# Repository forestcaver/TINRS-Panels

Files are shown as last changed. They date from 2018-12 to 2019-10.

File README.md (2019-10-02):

# TINRS-Panels
Tuesday Panel - verified and built

Wobbler Panel - verified and built

Rectangular Thing Panel - verified and built

Hedge Trimmer pcb and panel (Edgecutter with thonkiconn jacks and LP4OA1PBCTG led switch) - verified and built (one hole is not drilled - oops ! I'll update the gerber soon !)

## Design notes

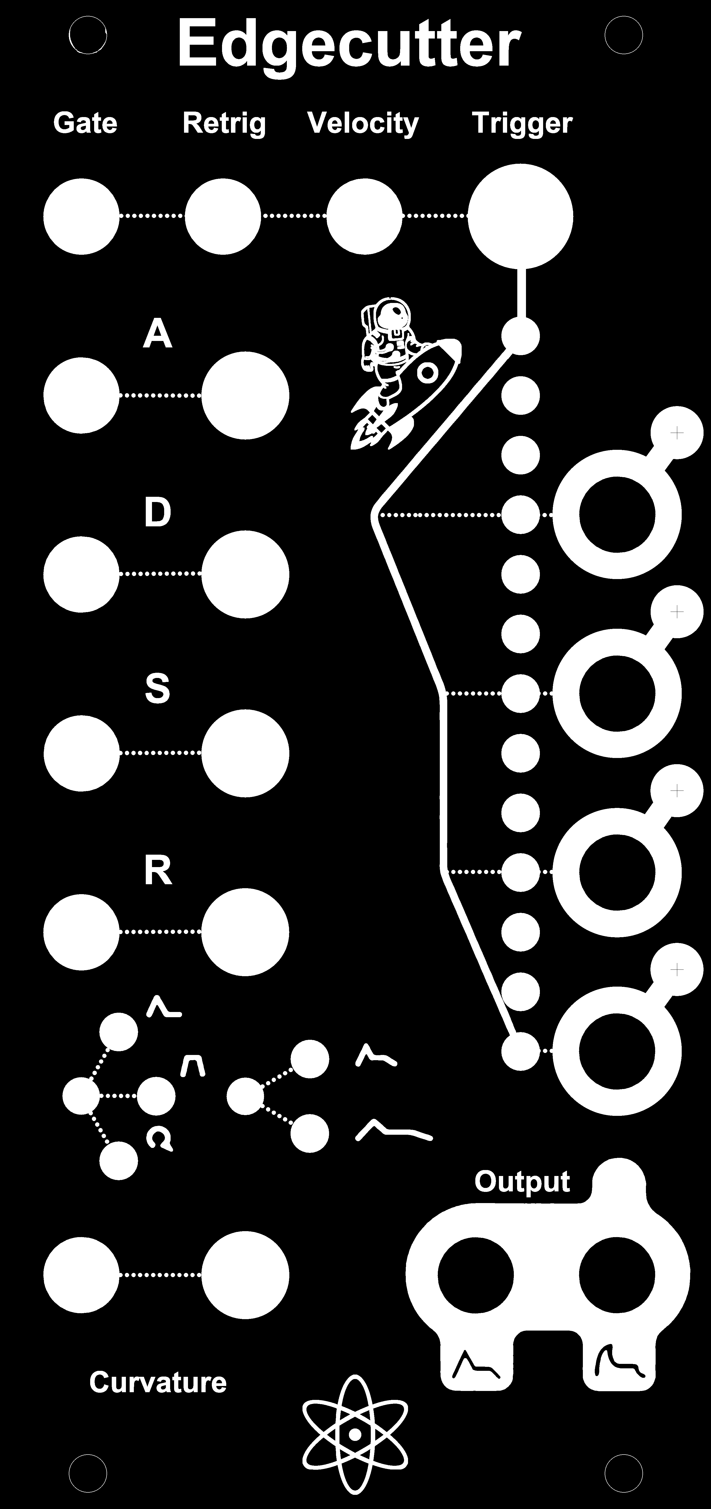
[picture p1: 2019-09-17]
HT_06.bmp

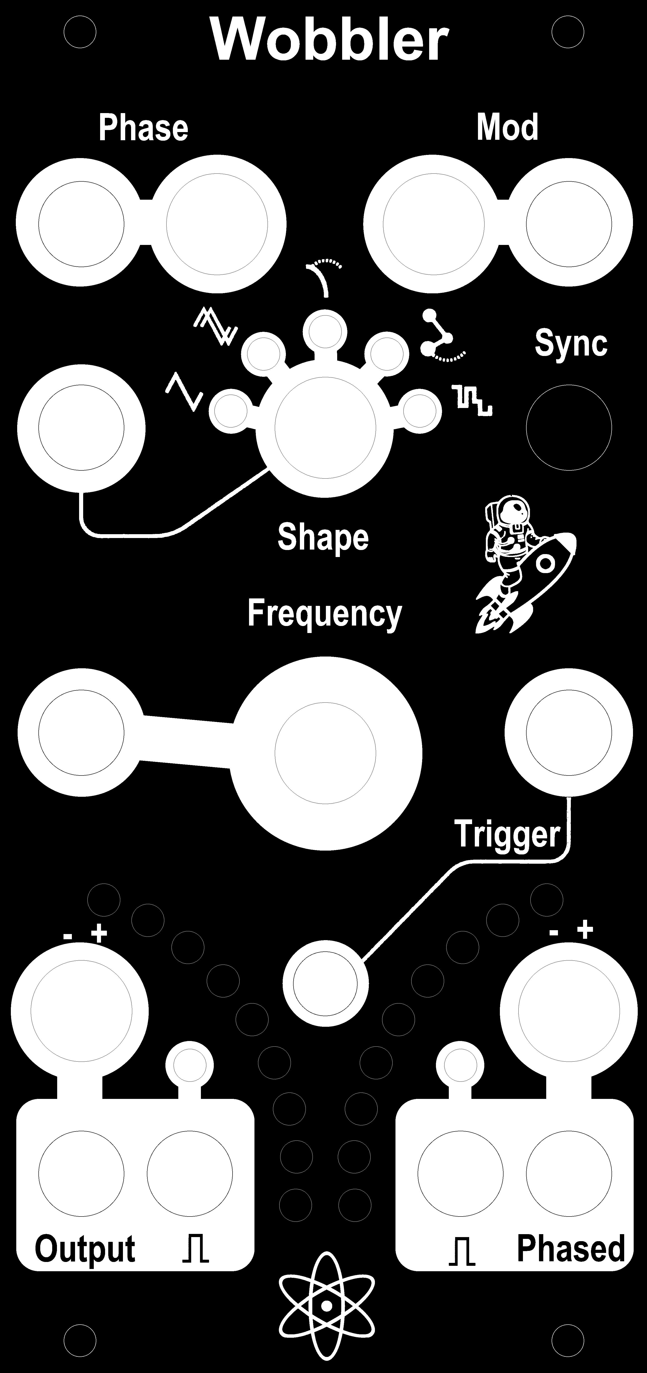
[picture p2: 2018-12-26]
AJH_Wob_01.bmp

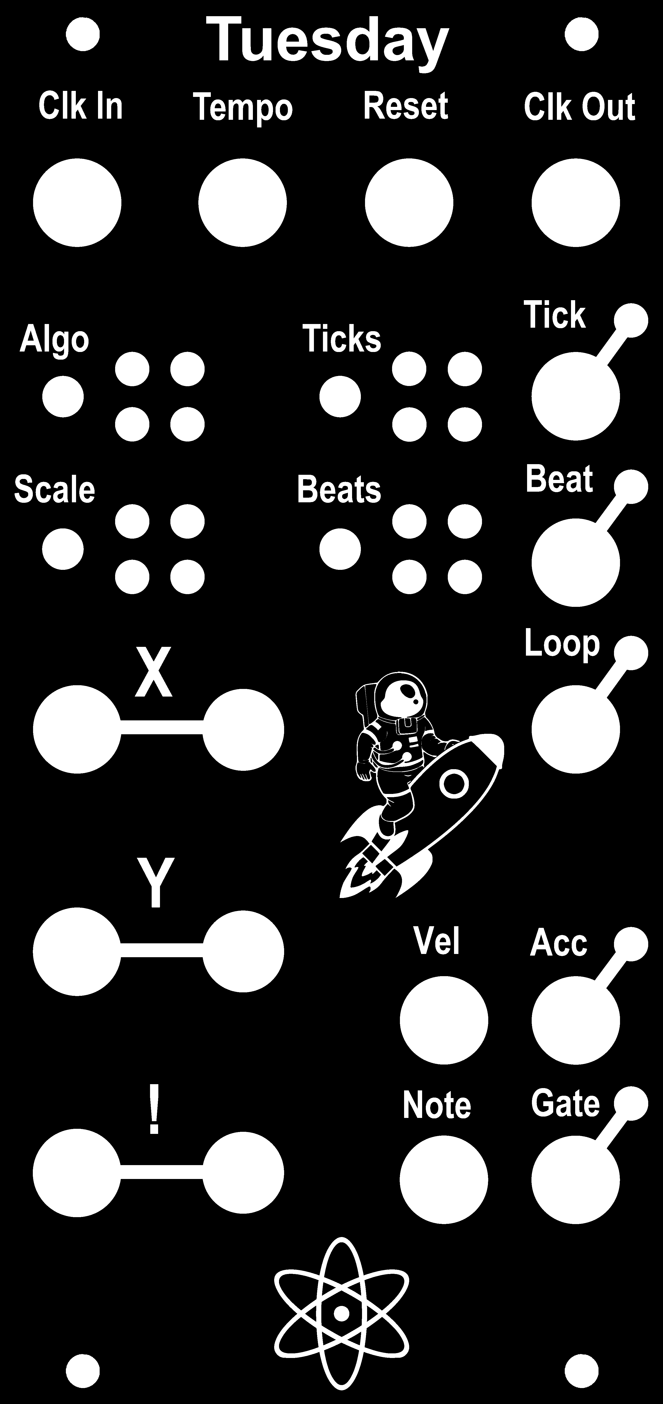
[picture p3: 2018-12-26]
Tue_Panel_AJH_01.bmp

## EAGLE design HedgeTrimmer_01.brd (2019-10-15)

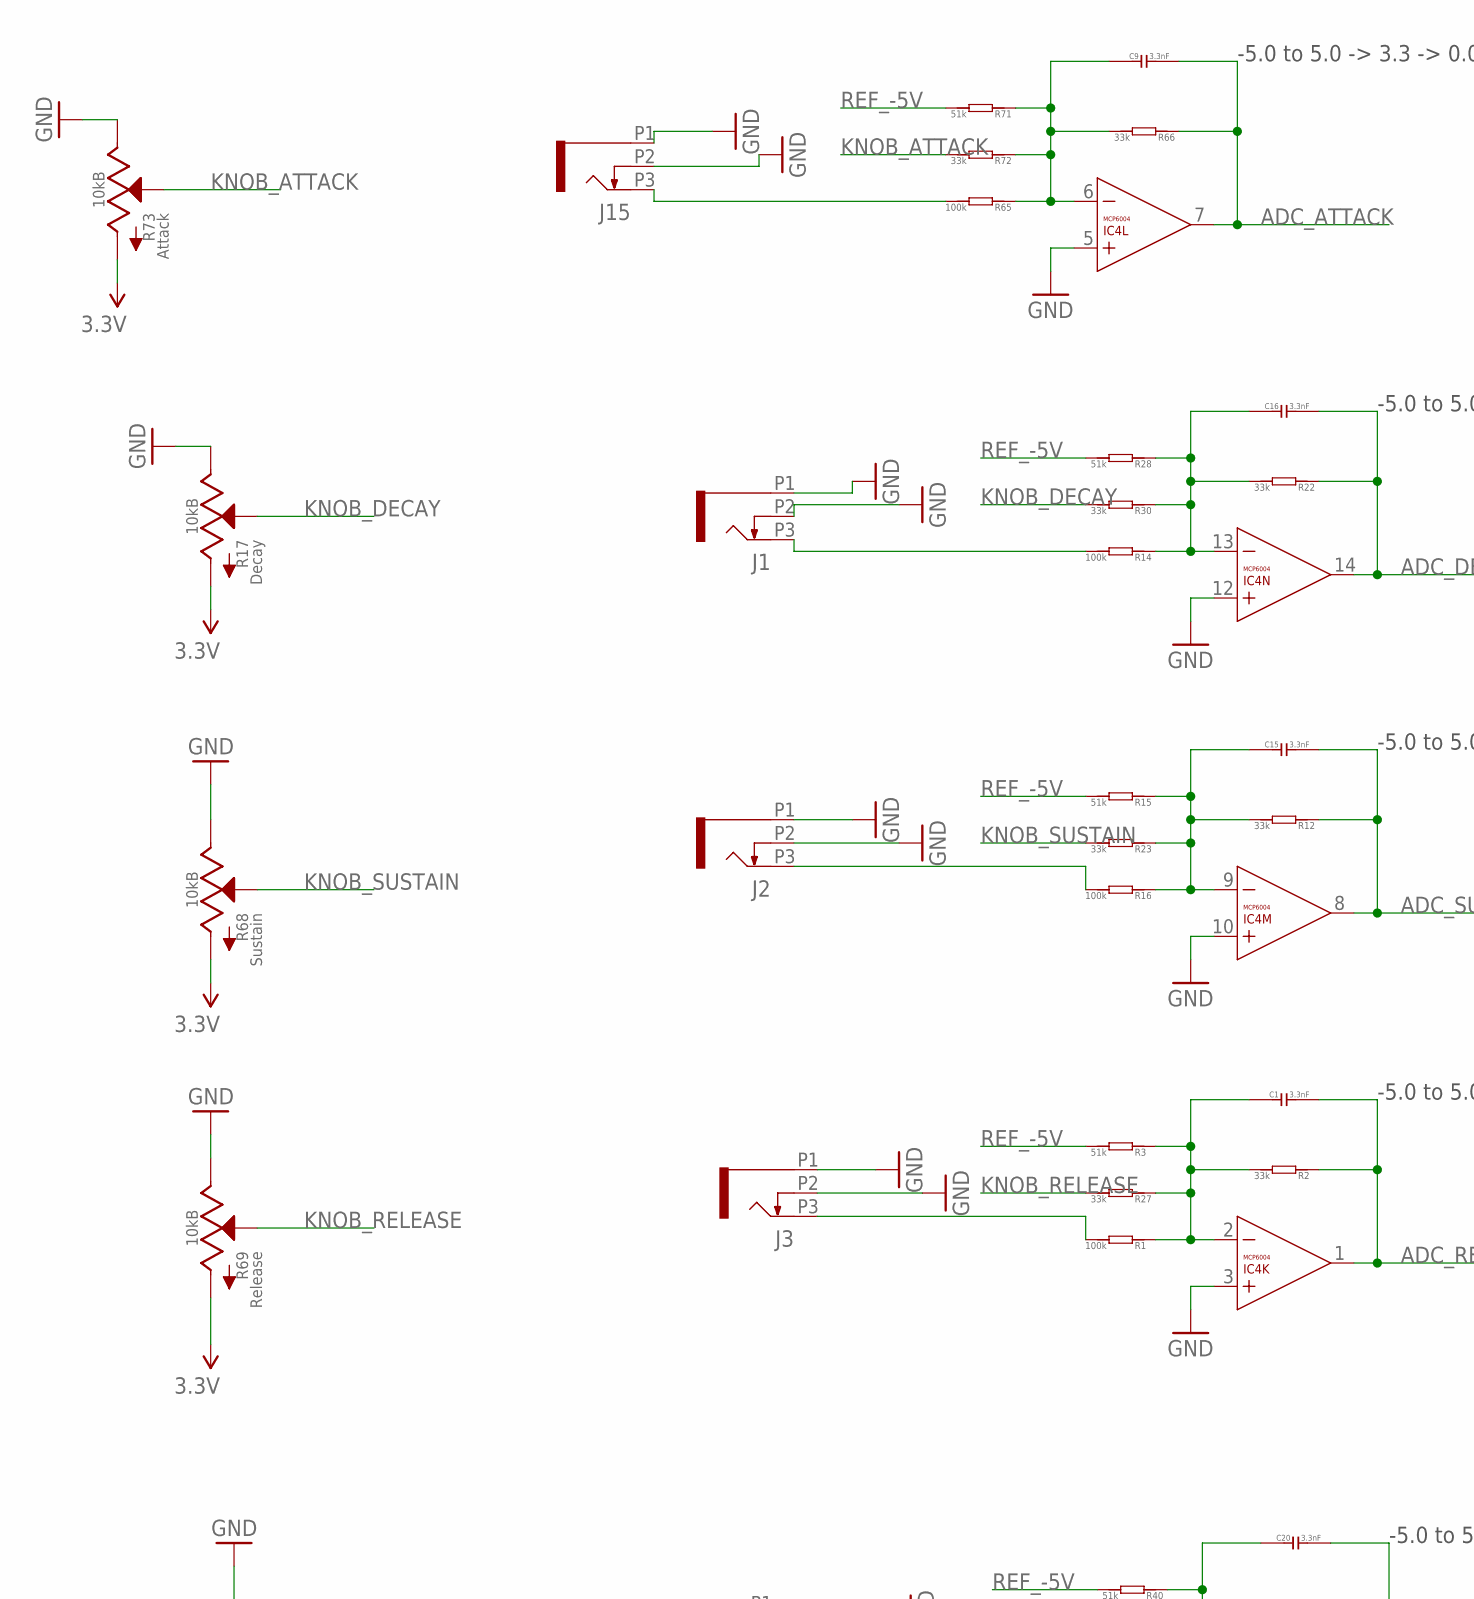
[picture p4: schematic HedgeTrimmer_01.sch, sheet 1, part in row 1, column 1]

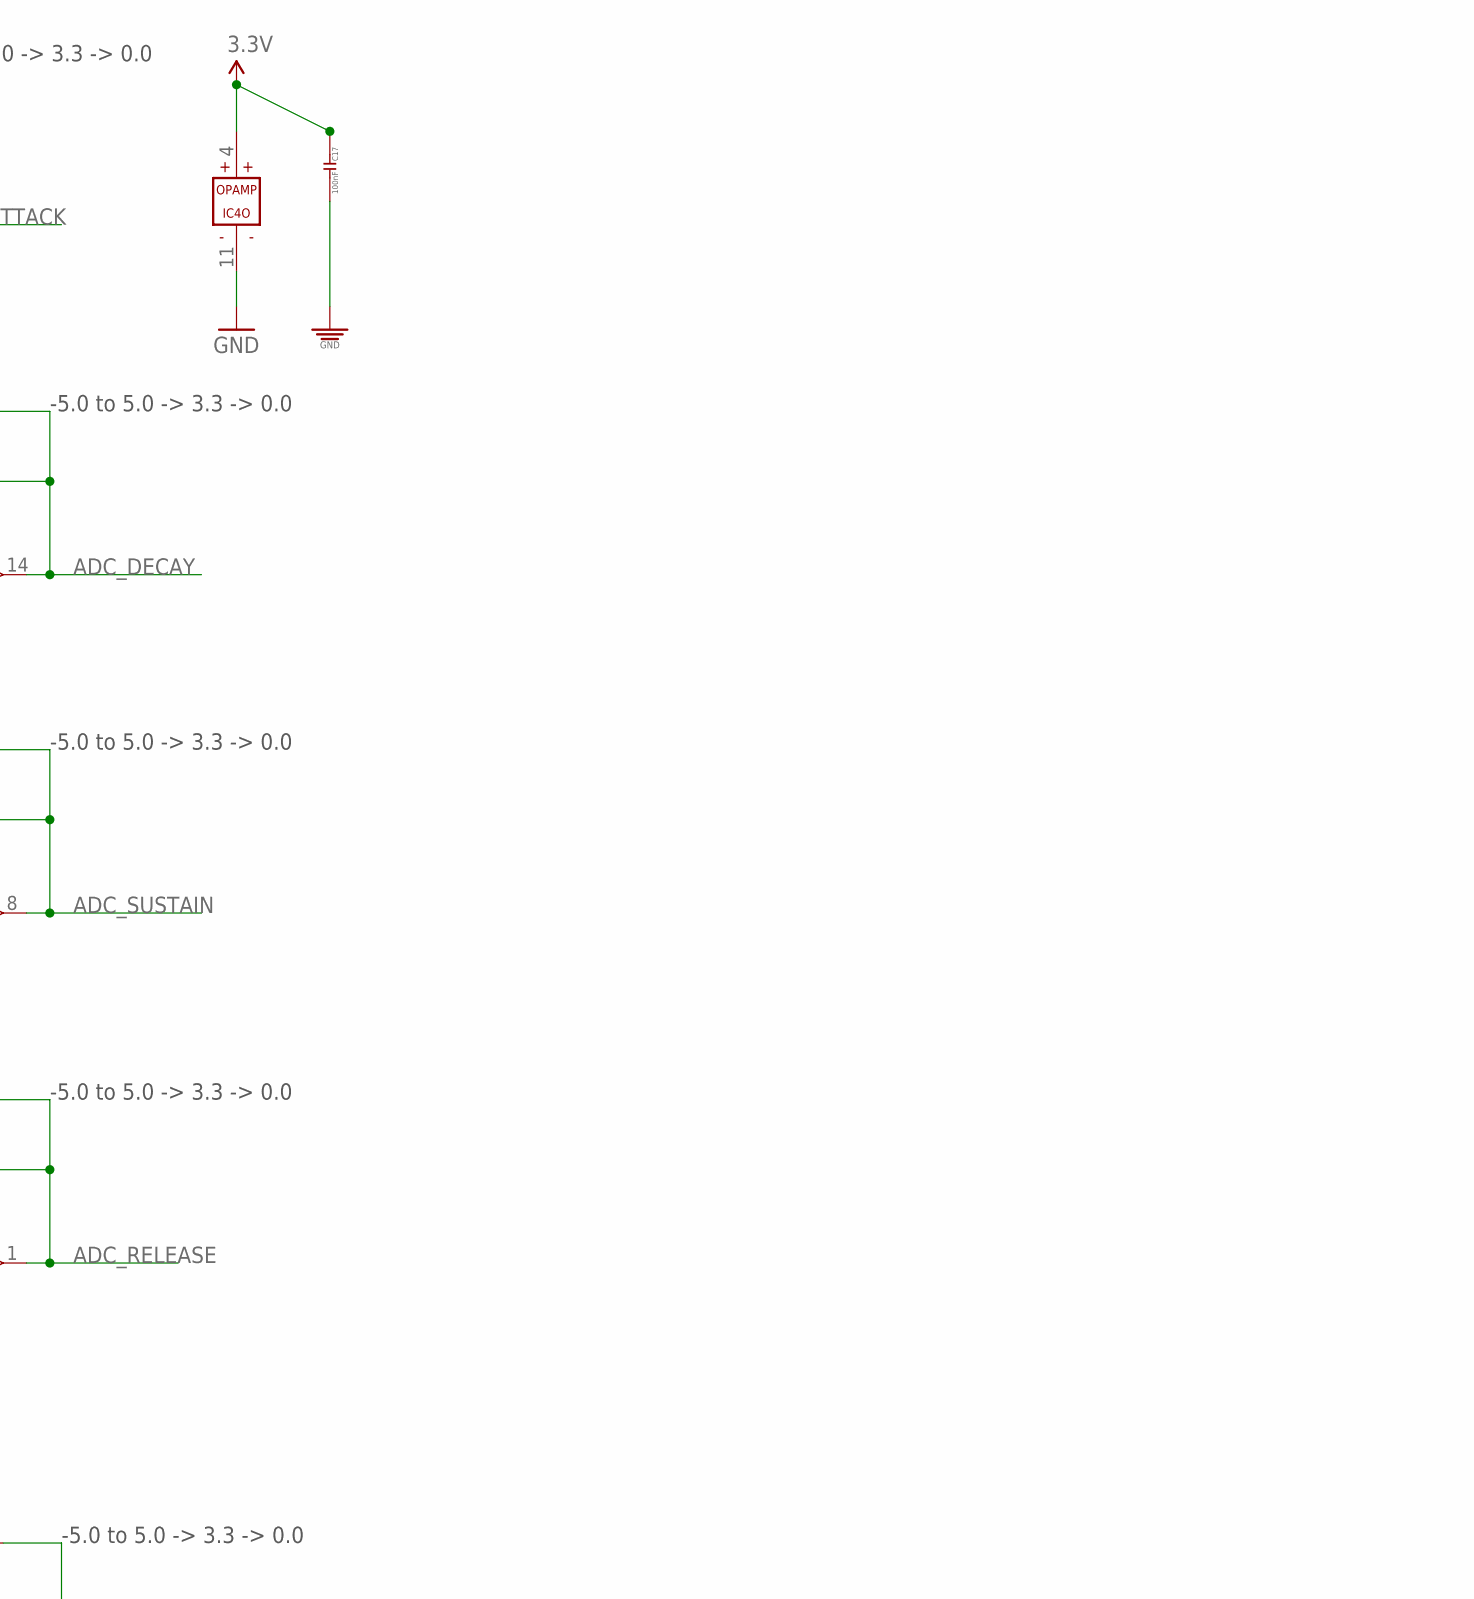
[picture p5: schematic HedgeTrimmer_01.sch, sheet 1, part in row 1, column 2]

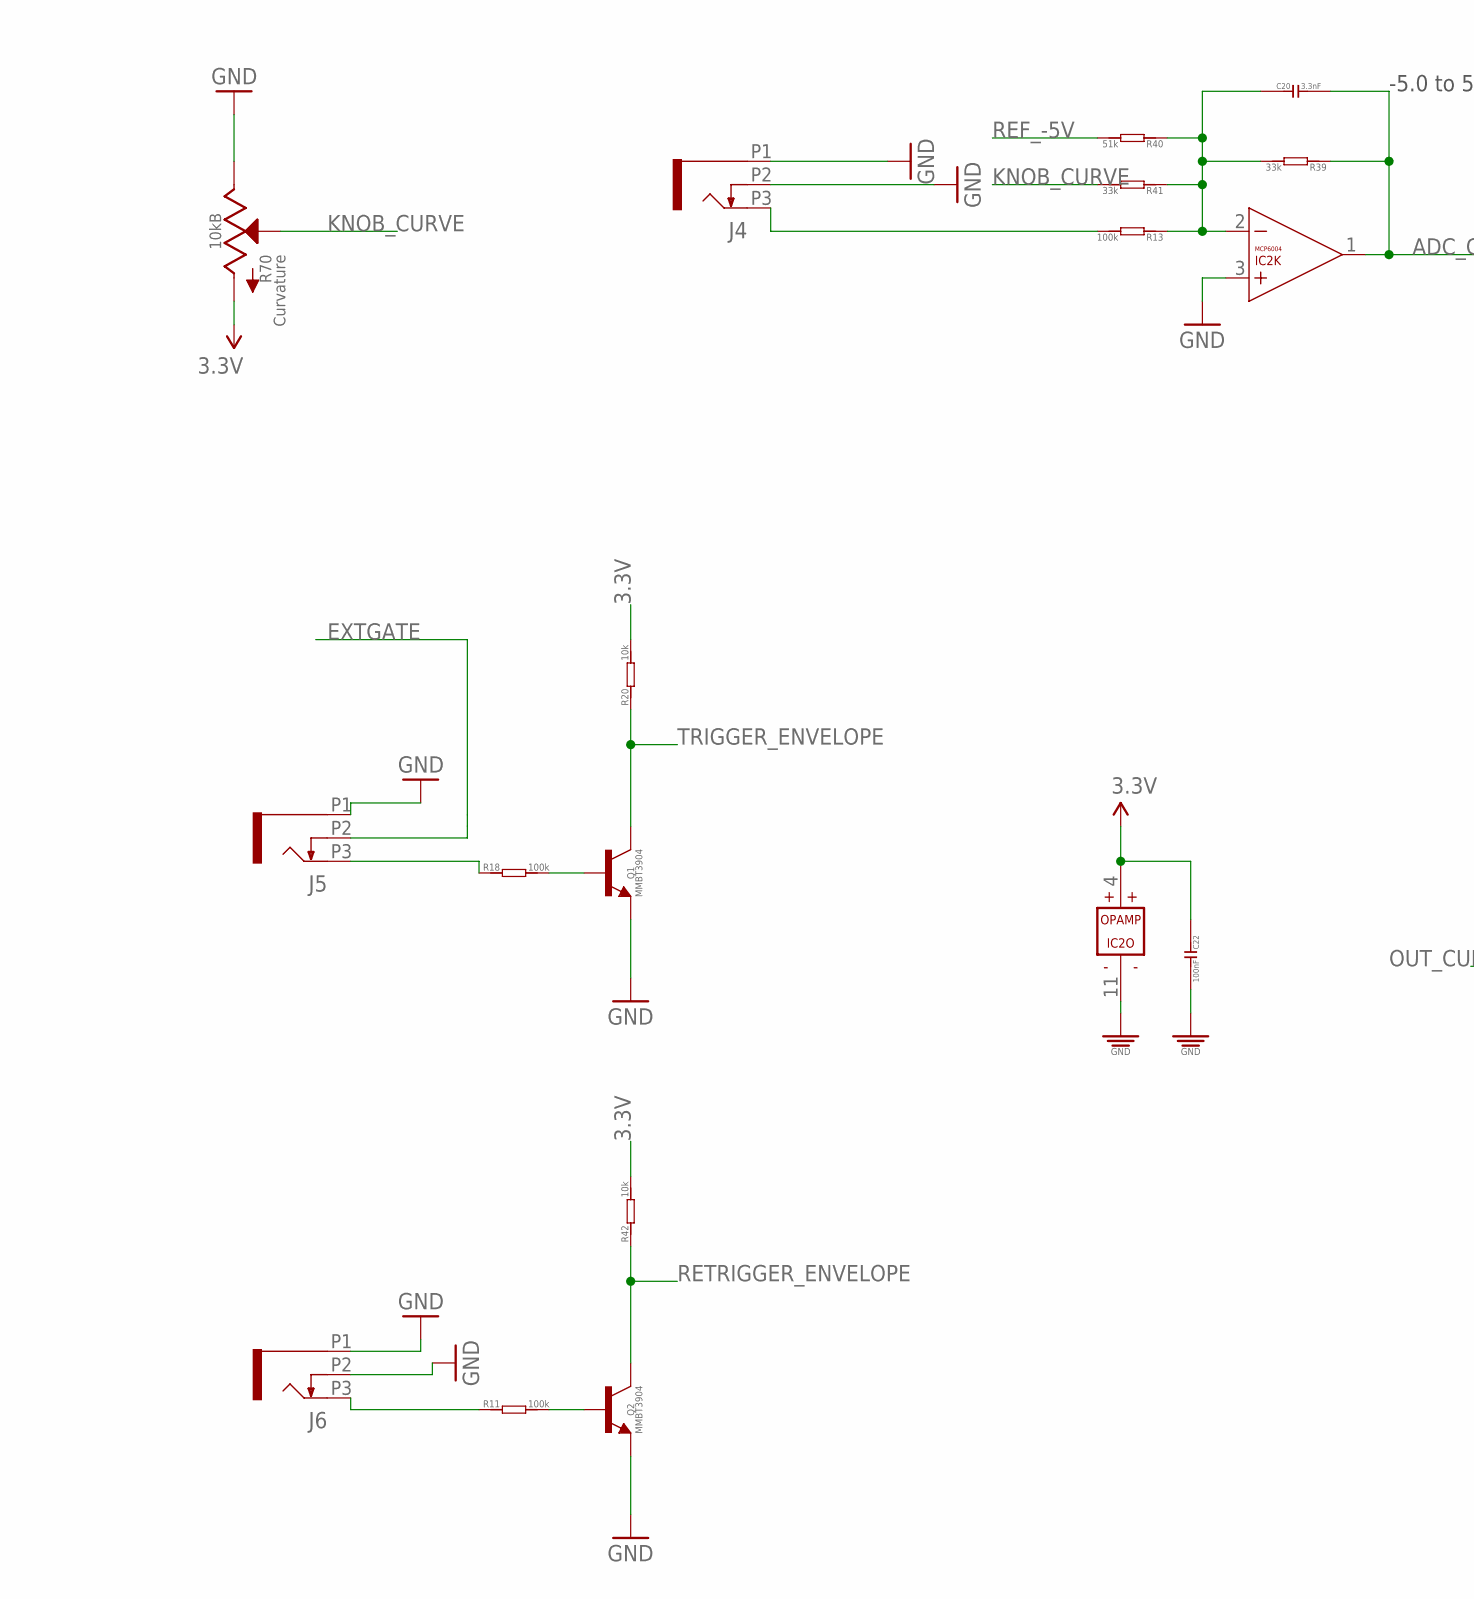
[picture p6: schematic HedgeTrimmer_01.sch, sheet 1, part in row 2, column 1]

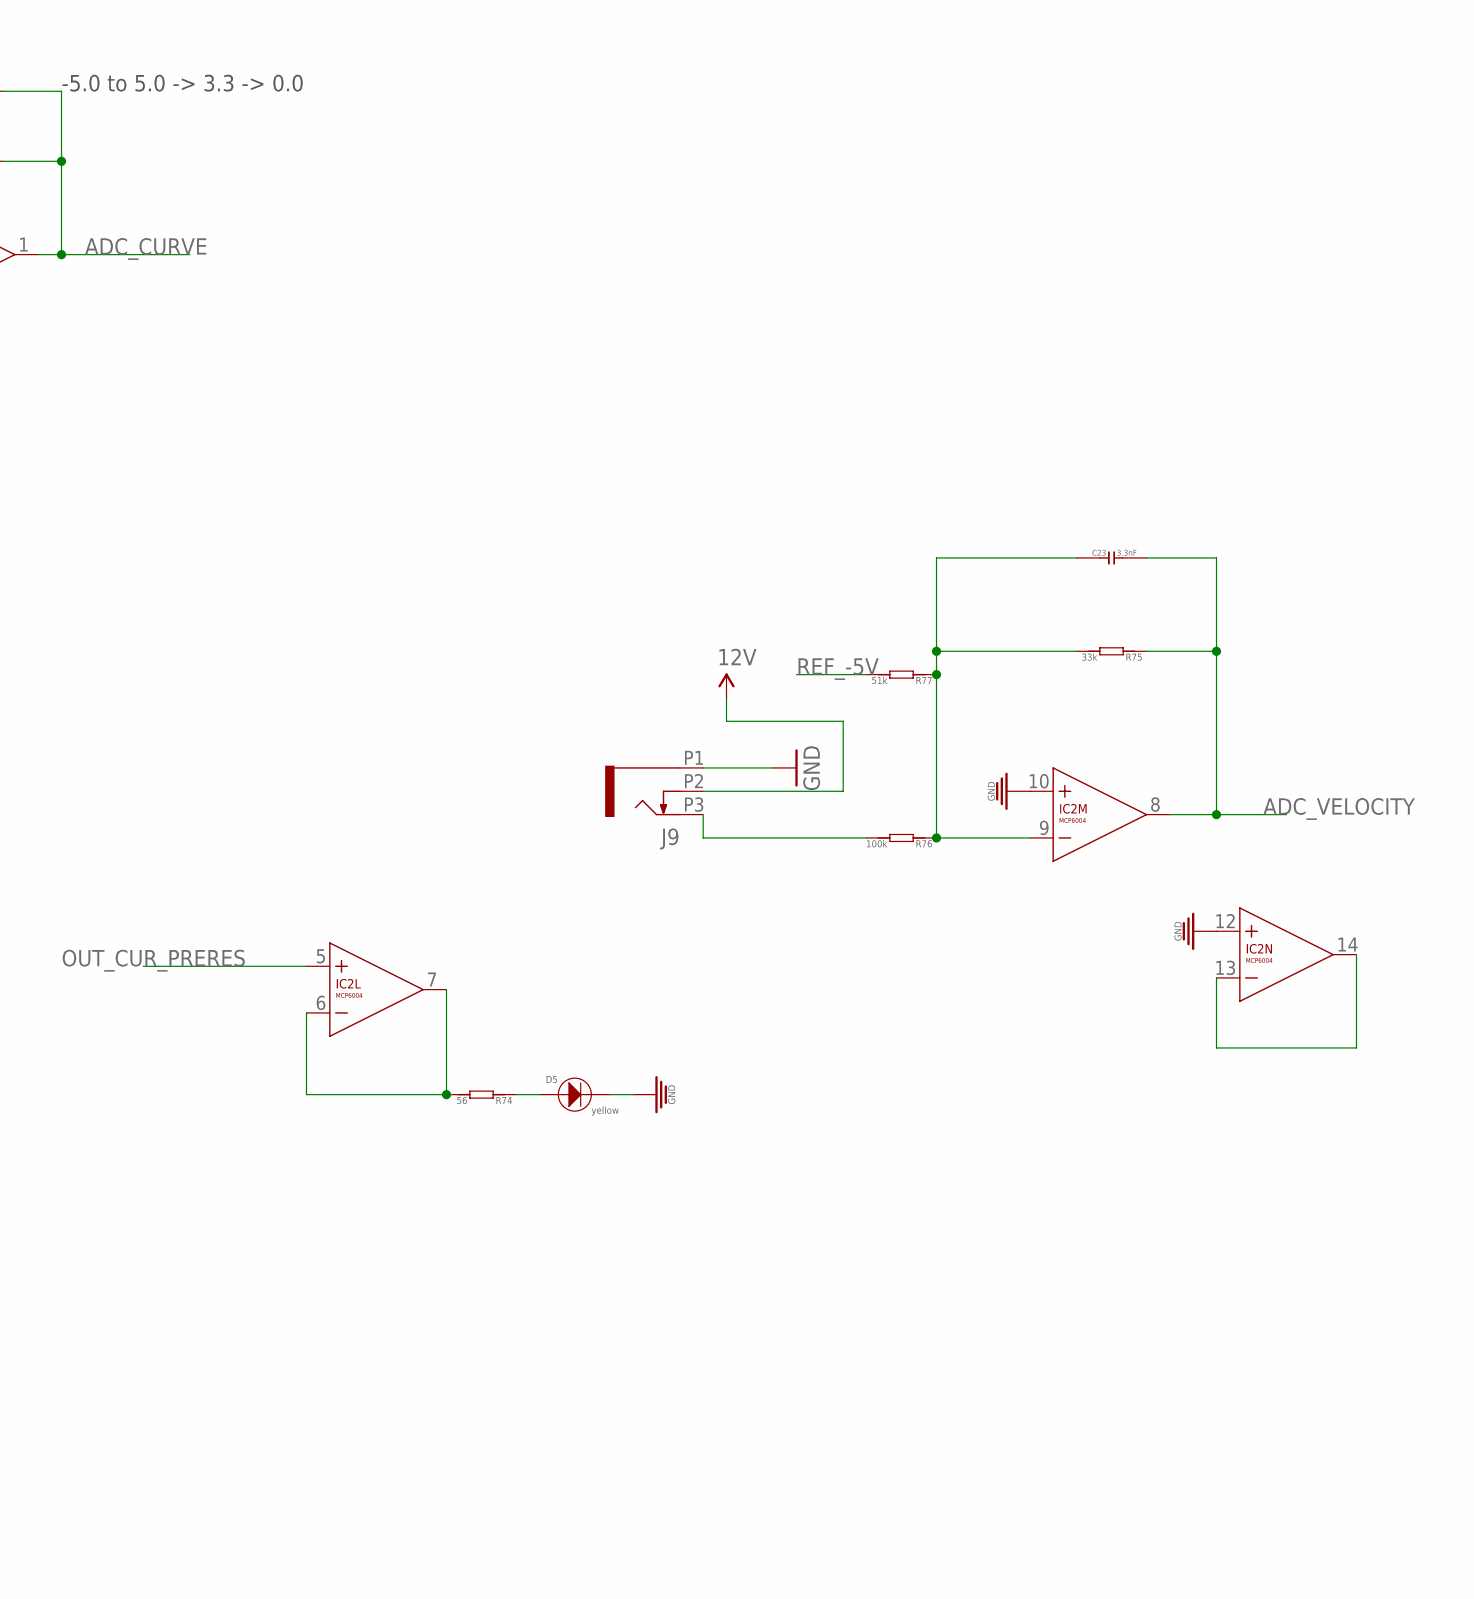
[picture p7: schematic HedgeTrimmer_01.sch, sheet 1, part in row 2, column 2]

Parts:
C1, C9, C15, C16, C20, C23: 3.3nF; C0603
C17, C22: 100nF; C0603; MPN MC0603F104Z160CT
D5: yellow; 3MMLED
IC2, IC4: MCP6004; SO14; MPN MCP6004-I/SL.
J1, J2, J3, J4, J5, J6, J9, J15: PJ301_THONKICONN8; WQP_PJ_301M8
Q1, Q2: MMBT3904; SOT23-BEC; MPN PMBT3904,215
R1, R11, R13, R14, R16, R18, R65, R76: 100k; R0603
R2, R12, R22, R23, R27, R30, R39, R41, R66, R72, R75: 33k; R0603
R3, R15, R28, R40, R71, R77: 51k; R0603
R17, R68, R69, R70, R73: 10kB; OG-POTS_ALPS_POT_VERTICAL
R20, R42: 10k; R0603
R74: 56; R0603

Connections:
3.3V: C17.1, C22.1, IC2.4 (V+), IC4.4 (V+), R17.P$3 (A), R20.2, R42.2, R68.P$3 (A), R69.P$3 (A), R70.P$3 (A), R73.P$3 (A); also elsewhere on the board
12V: J9.P2 (2); also elsewhere on the board
ADC_ATTACK: C9.2, IC4.7 (OUT), R66.1; also elsewhere on the board
ADC_CURVE: C20.2, IC2.1 (OUT), R39.1; also elsewhere on the board
ADC_DECAY: C16.2, IC4.14 (OUT), R22.1; also elsewhere on the board
ADC_RELEASE: C1.2, IC4.1 (OUT), R2.1; also elsewhere on the board
ADC_SUSTAIN: C15.2, IC4.8 (OUT), R12.1; also elsewhere on the board
ADC_VELOCITY: C23.2, IC2.8 (OUT), R75.1; also elsewhere on the board
EXTGATE: J5.P2 (2); also elsewhere on the board
GND: C17.2, C22.2, D5.-, IC2.3 (+IN), IC2.10 (+IN), IC2.11 (V-), IC2.12 (+IN), IC4.3 (+IN), IC4.5 (+IN), IC4.10 (+IN), IC4.11 (V-), IC4.12 (+IN), J1.P1 (1), J1.P2 (2), J2.P1 (1), J2.P2 (2), J3.P1 (1), J3.P2 (2), J4.P1 (1), J4.P2 (2), J5.P1 (1), J6.P1 (1), J6.P2 (2), J9.P1 (1), J15.P1 (1), J15.P2 (2), Q1.E, Q2.E, R17.P$1 (E), R68.P$1 (E), R69.P$1 (E), R70.P$1 (E), R73.P$1 (E); also elsewhere on the board
KNOB_ATTACK: R72.2, R73.P$2 (S)
KNOB_CURVE: R41.2, R70.P$2 (S)
KNOB_DECAY: R17.P$2 (S), R30.2
KNOB_RELEASE: R27.2, R69.P$2 (S)
KNOB_SUSTAIN: R23.2, R68.P$2 (S)
unnamed: J15.P3 (3), R65.2
unnamed: J2.P3 (3), R16.2
unnamed: C15.1, IC4.9 (-IN), R12.2, R15.1, R16.1, R23.1
unnamed: J3.P3 (3), R1.2
unnamed: C1.1, IC4.2 (-IN), R1.1, R2.2, R3.1, R27.1
unnamed: J1.P3 (3), R14.2
unnamed: J4.P3 (3), R13.2
unnamed: Q1.B, R18.2
unnamed: J5.P3 (3), R18.1
unnamed: IC2.6 (-IN), IC2.7 (OUT), R74.2
unnamed: J6.P3 (3), R11.1
unnamed: C9.1, IC4.6 (-IN), R65.1, R66.2, R71.1, R72.1
unnamed: IC2.13 (-IN), IC2.14 (OUT)
unnamed: J9.P3 (3), R76.2
unnamed: C16.1, IC4.13 (-IN), R14.1, R22.2, R28.1, R30.1
unnamed: Q2.B, R11.2
unnamed: C20.1, IC2.2 (-IN), R13.1, R39.2, R40.1, R41.1
unnamed: C23.1, IC2.9 (-IN), R75.2, R76.1, R77.1
unnamed: D5.+, R74.1
OUT_CUR_PRERES: IC2.5 (+IN); also elsewhere on the board
REF_-5V: R3.2, R15.2, R28.2, R40.2, R71.2, R77.2; also elsewhere on the board
RETRIGGER_ENVELOPE: Q2.C, R42.1; also elsewhere on the board
TRIGGER_ENVELOPE: Q1.C, R20.1; also elsewhere on the board

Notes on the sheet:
-5.0 to 5.0 -> 3.3 -> 0.0

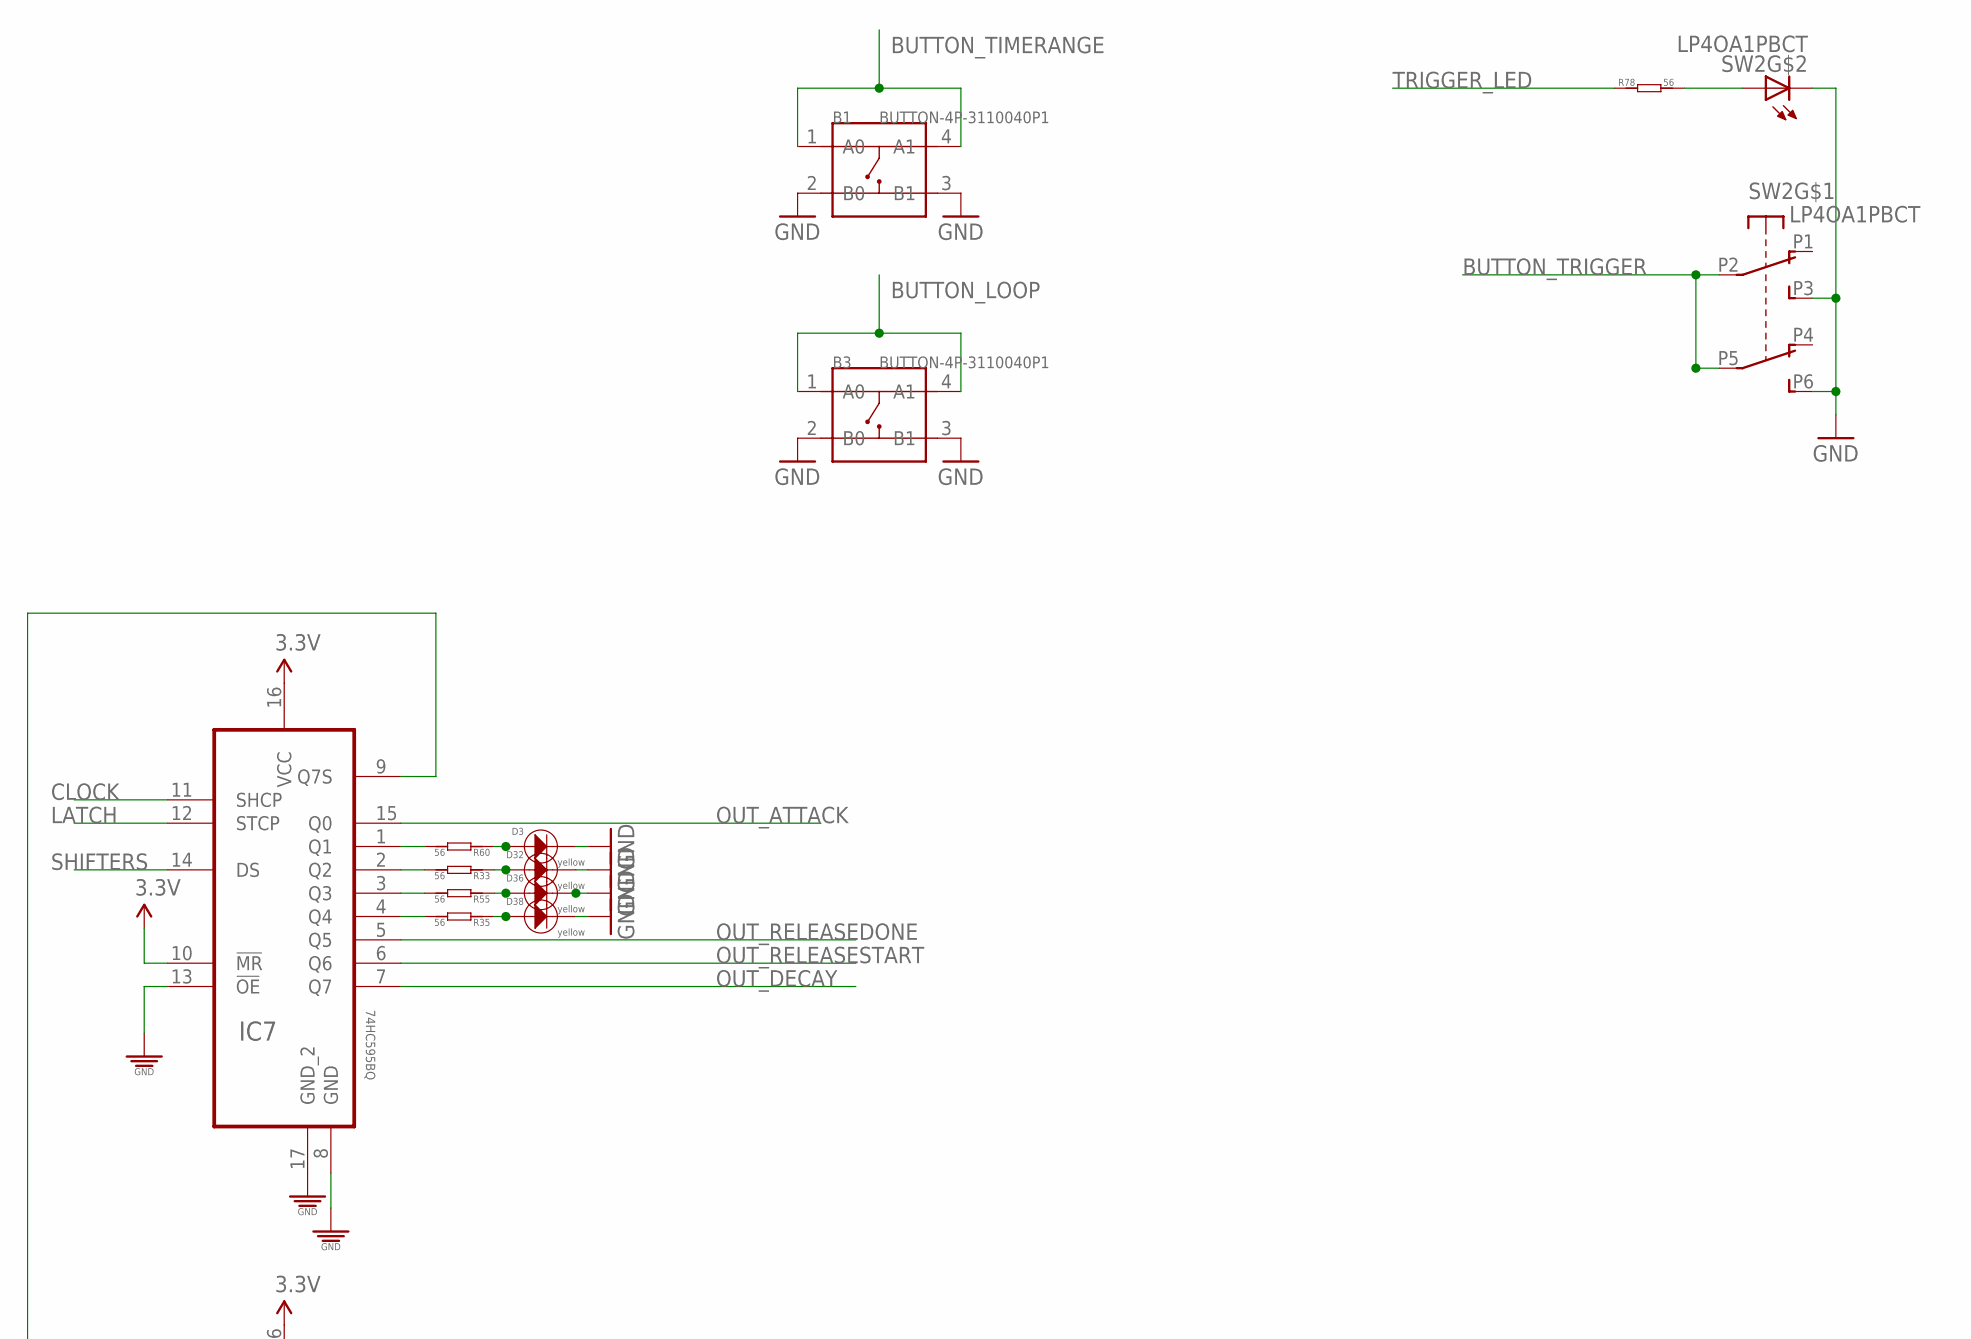
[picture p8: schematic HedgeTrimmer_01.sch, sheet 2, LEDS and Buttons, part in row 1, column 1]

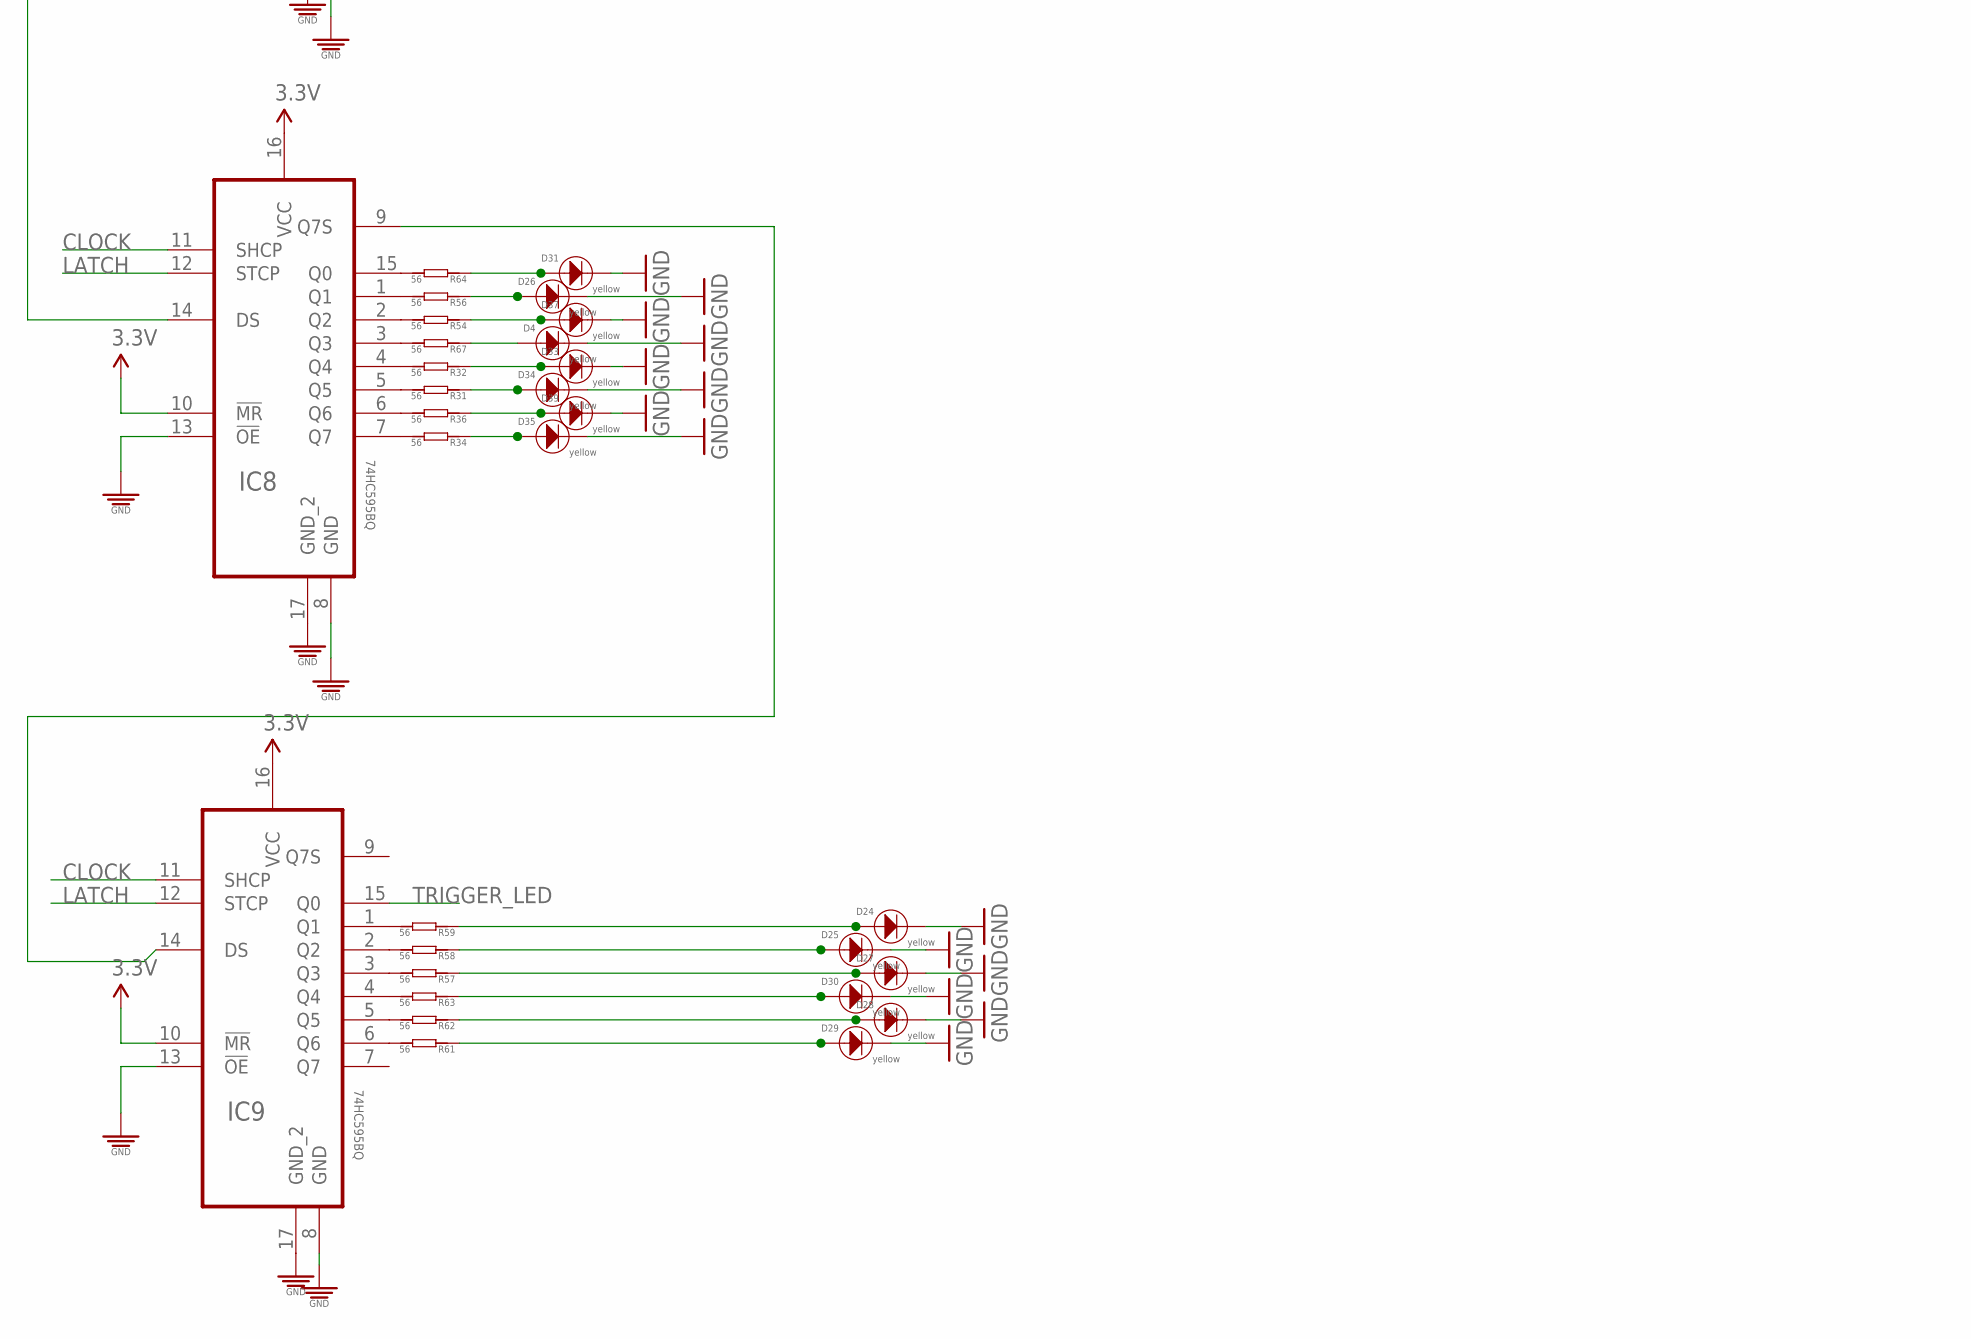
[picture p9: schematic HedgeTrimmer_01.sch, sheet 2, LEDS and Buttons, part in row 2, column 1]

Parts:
B1, B3: BUTTON-4P-3110040P1; 4P-6.0X6.0X5.0H
D3, D4, D24, D25, D26, D27, D28, D29, D30, D31, D32, D33, D34, D35, D36, D37, D38, D39: yellow; 3MMLED
IC7, IC8, IC9: 74HC595BQ; QFN50P250X350X100-17N
R31, R32, R33, R34, R35, R36, R54, R55, R56, R57, R58, R59, R60, R61, R62, R63, R64, R67, R78: 56; R0603
SW2: LP4OA1PBCT

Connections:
3.3V: IC7.10 (!MR), IC7.16 (VCC), IC8.10 (!MR), IC8.16 (VCC), IC9.10 (!MR), IC9.16 (VCC); also elsewhere on the board
BUTTON_LOOP: B3.1 (A0), B3.4 (A1); also elsewhere on the board
BUTTON_TIMERANGE: B1.1 (A0), B1.4 (A1); also elsewhere on the board
BUTTON_TRIGGER: SW2.P2 (A2), SW2.P5 (B2); also elsewhere on the board
CLOCK: IC7.11 (SHCP), IC8.11 (SHCP), IC9.11 (SHCP); also elsewhere on the board
GND: B1.2 (B0), B1.3 (B1), B3.2 (B0), B3.3 (B1), D3.-, D4.-, D24.-, D25.-, D26.-, D27.-, D28.-, D29.-, D30.-, D31.-, D32.-, D33.-, D34.-, D35.-, D36.-, D37.-, D38.-, D39.-, IC7.8 (GND), IC7.13 (!OE), IC7.17 (GND_2), IC8.8 (GND), IC8.13 (!OE), IC8.17 (GND_2), IC9.8 (GND), IC9.13 (!OE), IC9.17 (GND_2), SW2.L2, SW2.P3 (A3), SW2.P6 (B3); also elsewhere on the board
LATCH: IC7.12 (STCP), IC8.12 (STCP), IC9.12 (STCP); also elsewhere on the board
unnamed: R78.2, SW2.L1
unnamed: IC8.7 (Q7), R34.2
unnamed: IC8.15 (Q0), R64.2
unnamed: D28.+, R62.1
unnamed: D4.+, R67.1
unnamed: IC7.1 (Q1), R60.2
unnamed: D29.+, R61.1
unnamed: IC7.2 (Q2), R33.2
unnamed: IC7.3 (Q3), R55.2
unnamed: IC7.4 (Q4), R35.2
unnamed: IC8.1 (Q1), R56.2
unnamed: IC8.2 (Q2), R54.2
unnamed: IC8.3 (Q3), R67.2
unnamed: IC8.4 (Q4), R32.2
unnamed: IC8.5 (Q5), R31.2
unnamed: IC8.6 (Q6), R36.2
unnamed: IC9.1 (Q1), R59.2
unnamed: IC9.2 (Q2), R58.2
unnamed: D3.+, R60.1
unnamed: IC9.3 (Q3), R57.2
unnamed: IC9.4 (Q4), R63.2
unnamed: IC9.5 (Q5), R62.2
unnamed: IC9.6 (Q6), R61.2
unnamed: D27.+, R57.1
unnamed: D26.+, R56.1
unnamed: D25.+, R58.1
unnamed: D24.+, R59.1
unnamed: D30.+, R63.1
unnamed: D31.+, R64.1
unnamed: D32.+, R33.1
unnamed: D33.+, R32.1
unnamed: D34.+, R31.1
unnamed: D35.+, R34.1
unnamed: D36.+, R55.1
unnamed: D37.+, R54.1
unnamed: D38.+, R35.1
unnamed: D39.+, R36.1
OUT_ATTACK: IC7.15 (Q0); also elsewhere on the board
OUT_DECAY: IC7.7 (Q7); also elsewhere on the board
OUT_RELEASEDONE: IC7.5 (Q5); also elsewhere on the board
OUT_RELEASESTART: IC7.6 (Q6); also elsewhere on the board
SHIFTER1TO2: IC7.9 (Q7S), IC8.14 (DS)
SHIFTER2TO3: IC8.9 (Q7S), IC9.14 (DS)
SHIFTERS: IC7.14 (DS); also elsewhere on the board
TRIGGER_LED: IC9.15 (Q0), R78.1

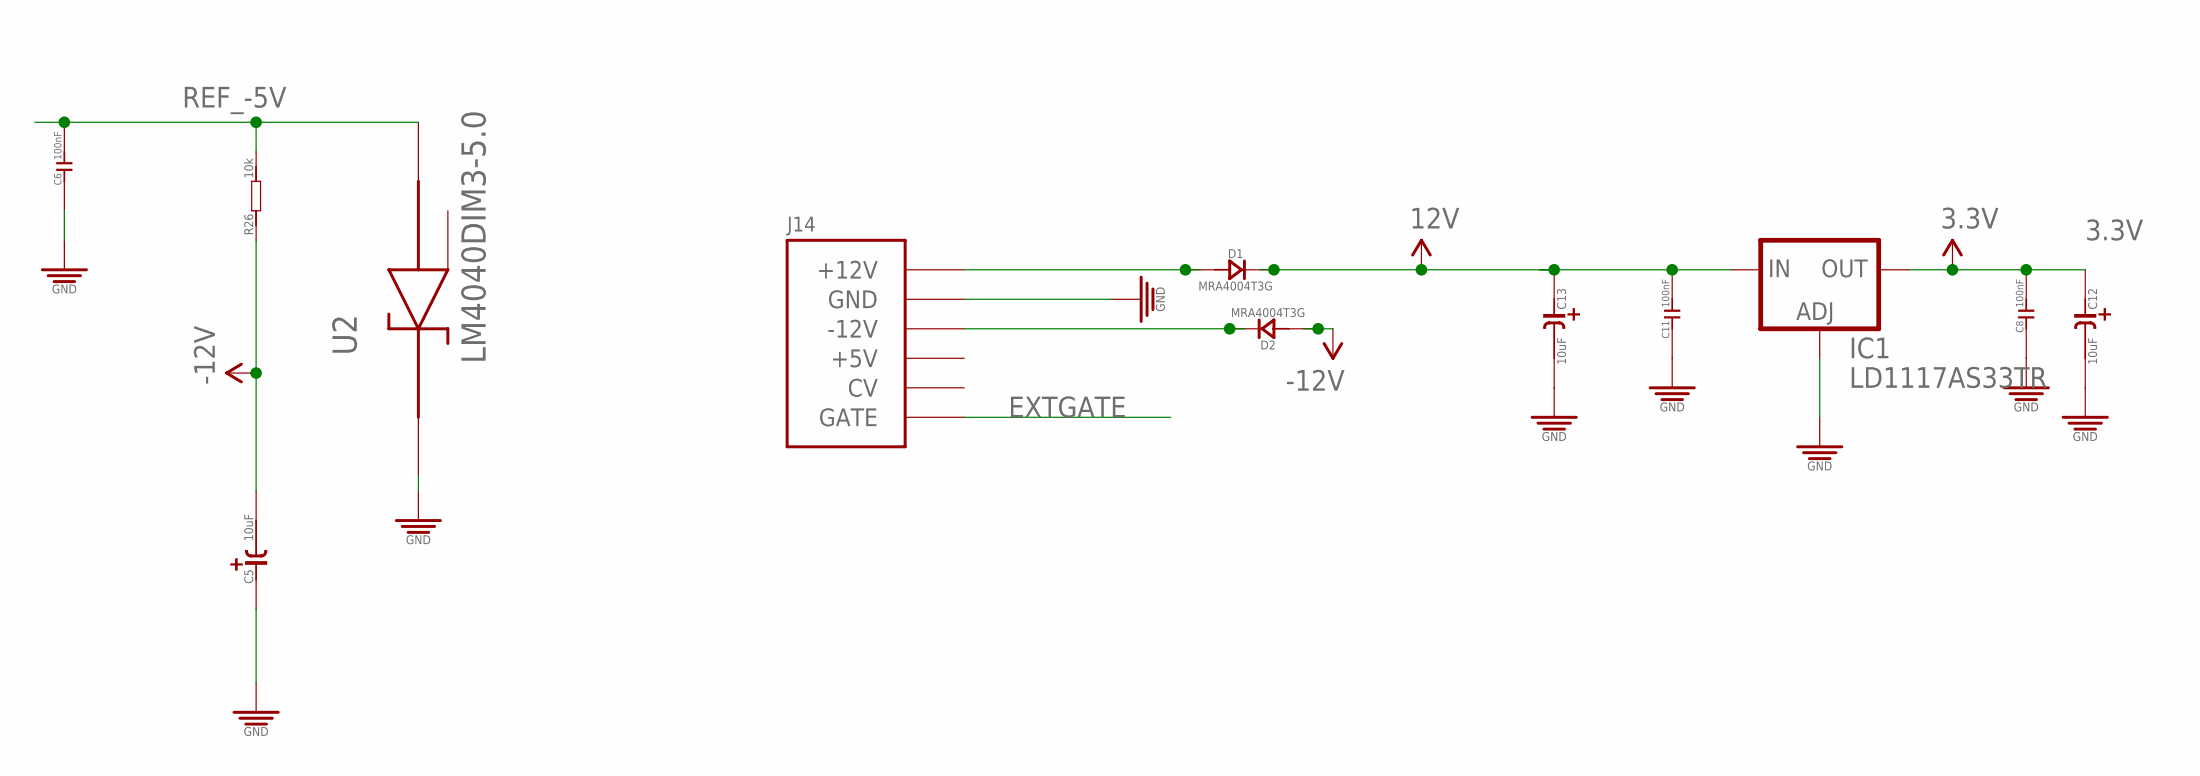
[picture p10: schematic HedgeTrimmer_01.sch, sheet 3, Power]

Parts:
C5, C12, C13: 10uF; CASE-A_3216; MPN TAJB106K020RNJ
C6: 100nF; C0603; MPN 06035C104KAT2A
C8, C11: 100nF; C0603; MPN MC0603F104Z160CT
D1, D2: MRA4004T3G; DO-214AC; MPN US1G-E3/5AT
IC1: LD1117AS33TR; SOT223; MPN LD1117AS33TR
J14: POWERSMT; 2X08_SMT_HEADER
R26: 10k; R0603
U2: LM4040DIM3-5.0; SOT95P237X112-3N

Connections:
3.3V: C8.2, C12.+ (1), IC1.2 (OUT), IC1.4 (OUT); also elsewhere on the board
12V: C11.2, C13.+ (1), D1.2 (-), IC1.3 (IN); also elsewhere on the board
-12V: C5.- (2), D2.1 (+), R26.1; also elsewhere on the board
EXTGATE: J14.15 (GATE), J14.16 (GATE); also elsewhere on the board
GND: C5.+ (1), C6.1, C8.1, C11.1, C12.- (2), C13.- (2), IC1.1 (ADJ), J14.3 (GND), J14.4 (GND), J14.5 (GND), J14.6 (GND), J14.7 (GND), J14.8 (GND), U2.1 (CATHODE); also elsewhere on the board
unnamed: D1.1 (+), J14.9 (+12V), J14.10 (+12V)
unnamed: D2.2 (-), J14.1 (-12V), J14.2 (-12V)
REF_-5V: C6.2, R26.2, U2.2 (ANODE); also elsewhere on the board

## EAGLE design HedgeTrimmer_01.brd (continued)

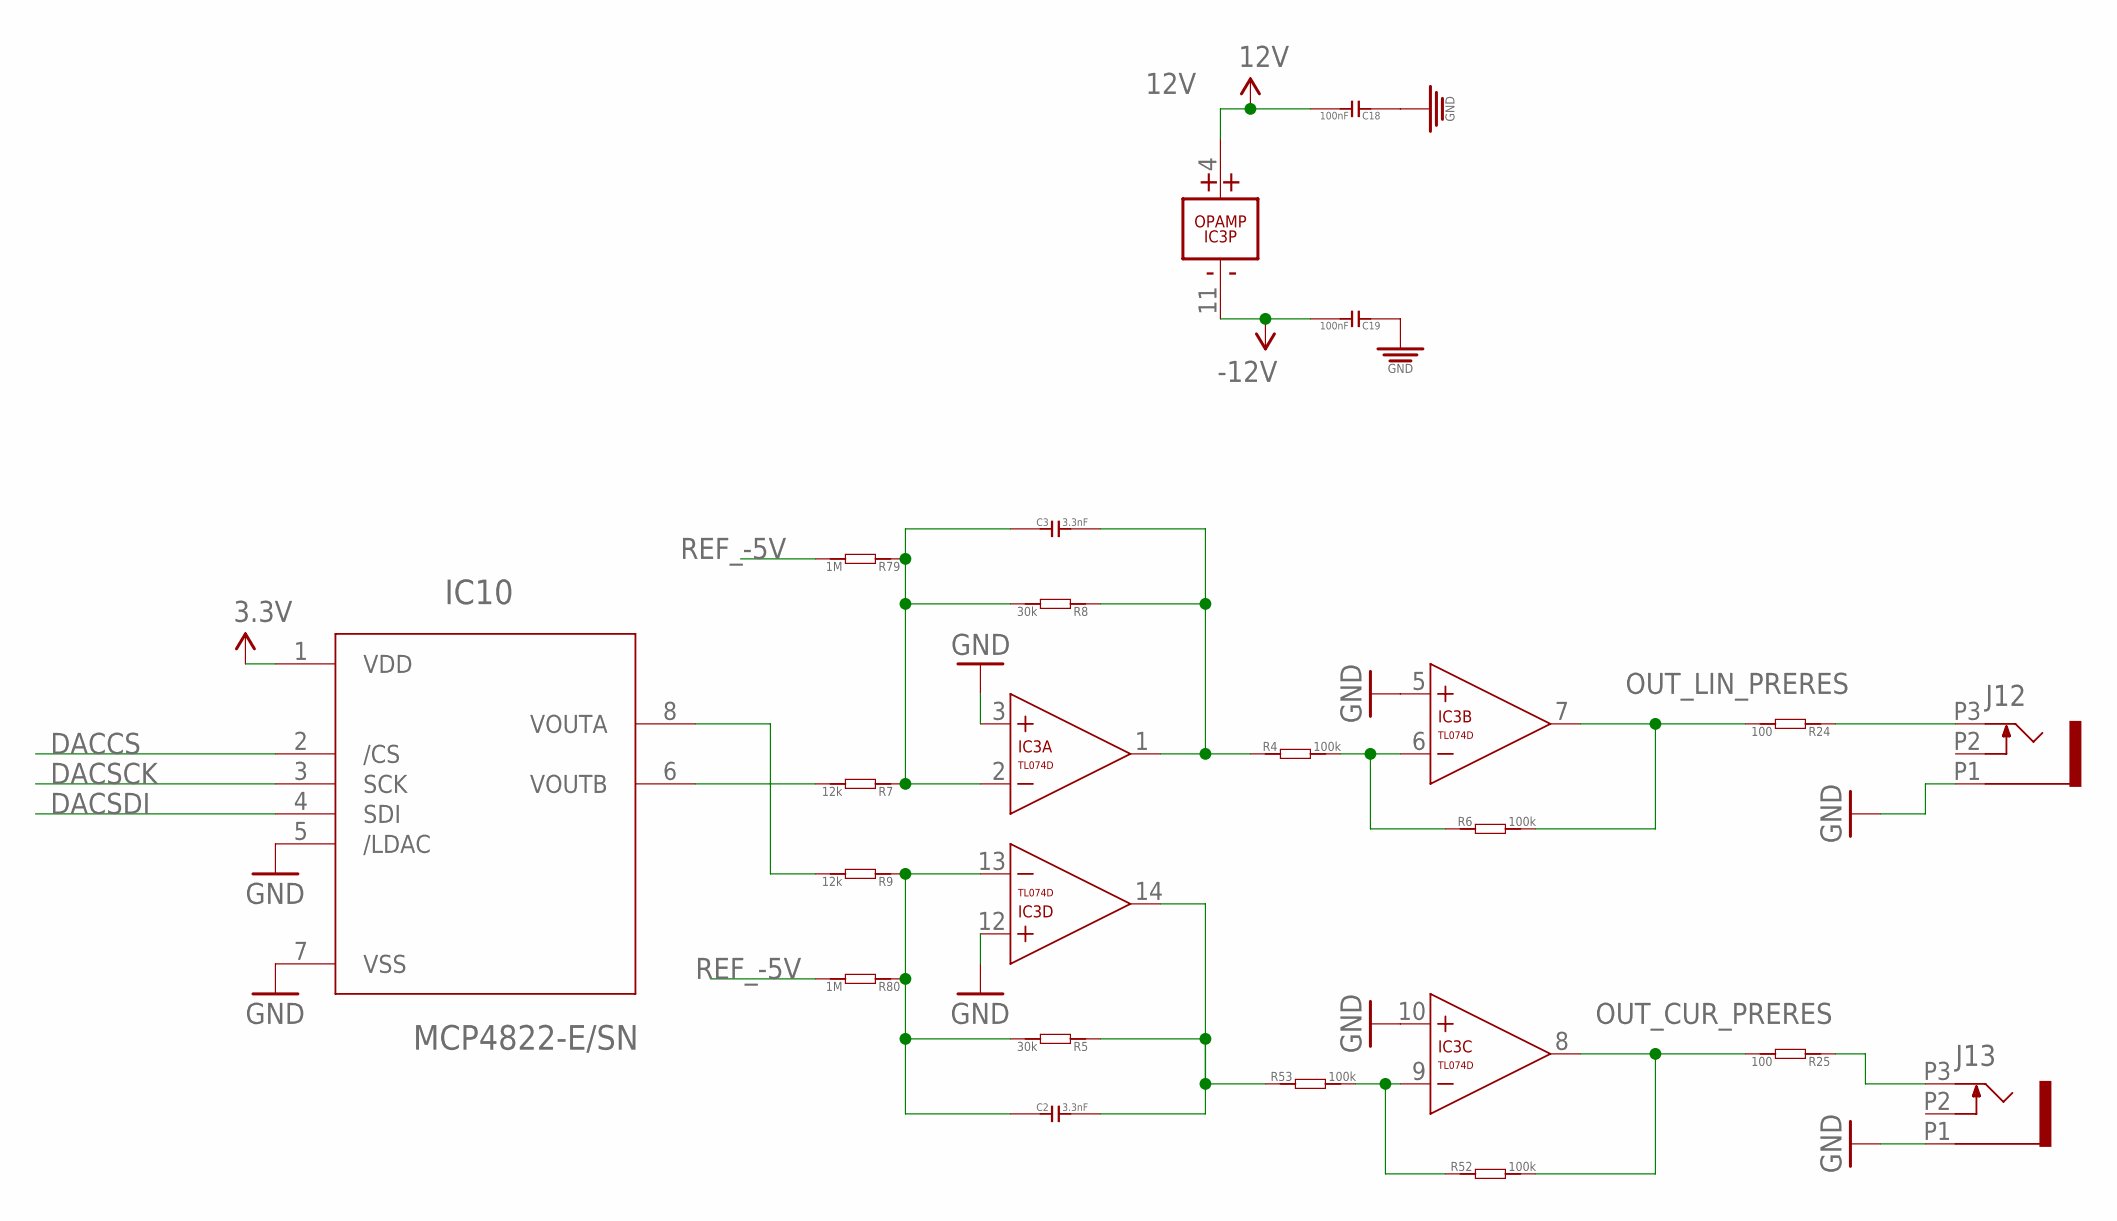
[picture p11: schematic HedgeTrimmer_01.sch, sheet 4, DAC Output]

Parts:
C2, C3: 3.3nF; C0603
C18, C19: 100nF; C0603; MPN MC0603F104Z160CT
IC3: TL074D; SO14; MPN TL074CD
IC10: MCP4822-E/SN; SOIC8-N_MC
J12, J13: PJ301_THONKICONN8; WQP_PJ_301M8
R4, R6, R52, R53: 100k; R0603
R5, R8: 30k; R0603
R7, R9: 12k; R0603
R24, R25: 100; R0603
R79, R80: 1M; R0603

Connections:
3.3V: IC10.1 (VDD); also elsewhere on the board
12V: C18.2, IC3.4 (V+); also elsewhere on the board
-12V: C19.2, IC3.11 (V-); also elsewhere on the board
DACA_INPUTSUMMER: C2.1, IC3.13 (-IN), R5.2, R9.1, R80.1
DACB_INPUTSUMMER: C3.1, IC3.2 (-IN), R7.1, R8.2, R79.1
DACCS: IC10.2 (/CS); also elsewhere on the board
DACSCK: IC10.3 (SCK); also elsewhere on the board
DACSDI: IC10.4 (SDI); also elsewhere on the board
GND: C18.1, C19.1, IC3.3 (+IN), IC3.5 (+IN), IC3.10 (+IN), IC3.12 (+IN), IC10.5 (/LDAC), IC10.7 (VSS), J12.P1 (1), J13.P1 (1); also elsewhere on the board
unnamed: IC3.6 (-IN), R4.2, R6.1
unnamed: IC10.8 (VOUTA), R9.2
unnamed: IC10.6 (VOUTB), R7.2
unnamed: J12.P3 (3), R24.1
unnamed: IC3.9 (-IN), R52.1, R53.2
unnamed: C3.2, IC3.1 (OUT), R4.1, R8.1
unnamed: J13.P3 (3), R25.1
unnamed: C2.2, IC3.14 (OUT), R5.1, R53.1
OUT_CUR_PRERES: IC3.8 (OUT), R25.2, R52.2; also elsewhere on the board
OUT_LIN_PRERES: IC3.7 (OUT), R6.2, R24.2
REF_-5V: R79.2, R80.2; also elsewhere on the board

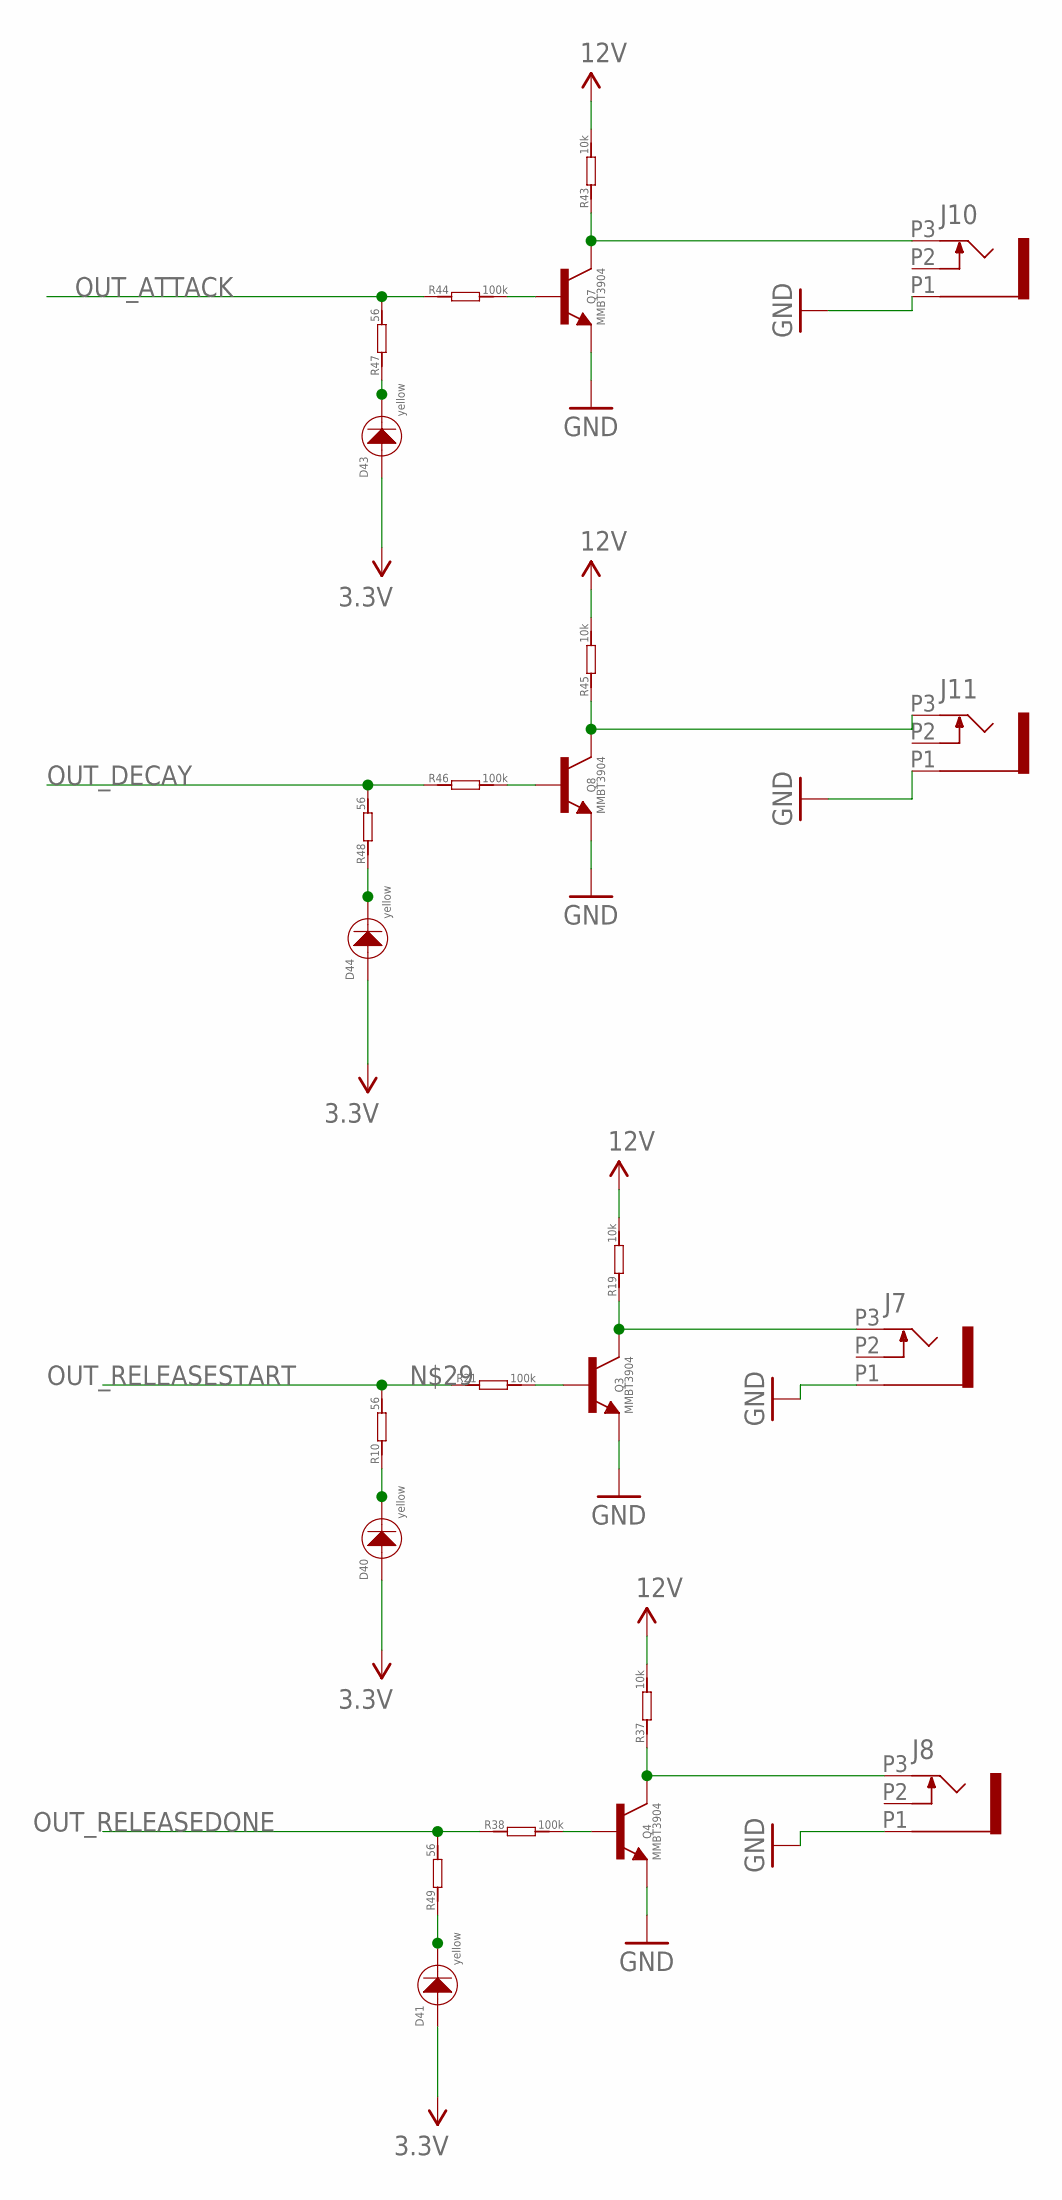
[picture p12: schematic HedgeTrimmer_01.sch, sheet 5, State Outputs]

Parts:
D40, D41, D43, D44: yellow; 3MMLED
J7, J8, J10, J11: PJ301_THONKICONN8; WQP_PJ_301M8
Q3, Q4, Q7, Q8: MMBT3904; SOT23-BEC; MPN PMBT3904,215
R10, R47, R48, R49: 56; R0603
R19, R37, R43, R45: 10k; R0603
R21, R38, R44, R46: 100k; R0603

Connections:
3.3V: D40.+, D41.+, D43.+, D44.+; also elsewhere on the board
12V: R19.2, R37.2, R43.2, R45.2; also elsewhere on the board
D21: D43.-, R47.1
GND: J7.P1 (1), J8.P1 (1), J10.P1 (1), J11.P1 (1), Q3.E, Q4.E, Q7.E, Q8.E; also elsewhere on the board
unnamed: D40.-, R10.1
unnamed: Q3.B, R21.2
unnamed: J7.P3 (3), Q3.C, R19.1
unnamed: D41.-, R49.1
unnamed: D44.-, R48.1
unnamed: Q4.B, R38.2
unnamed: J8.P3 (3), Q4.C, R37.1
unnamed: Q7.B, R44.2
unnamed: J10.P3 (3), Q7.C, R43.1
unnamed: Q8.B, R46.2
unnamed: J11.P3 (3), Q8.C, R45.1
OUT_ATTACK: R44.1, R47.2; also elsewhere on the board
OUT_DECAY: R46.1, R48.2; also elsewhere on the board
OUT_RELEASEDONE: R38.1, R49.2; also elsewhere on the board
OUT_RELEASESTART: R10.2, R21.1; also elsewhere on the board

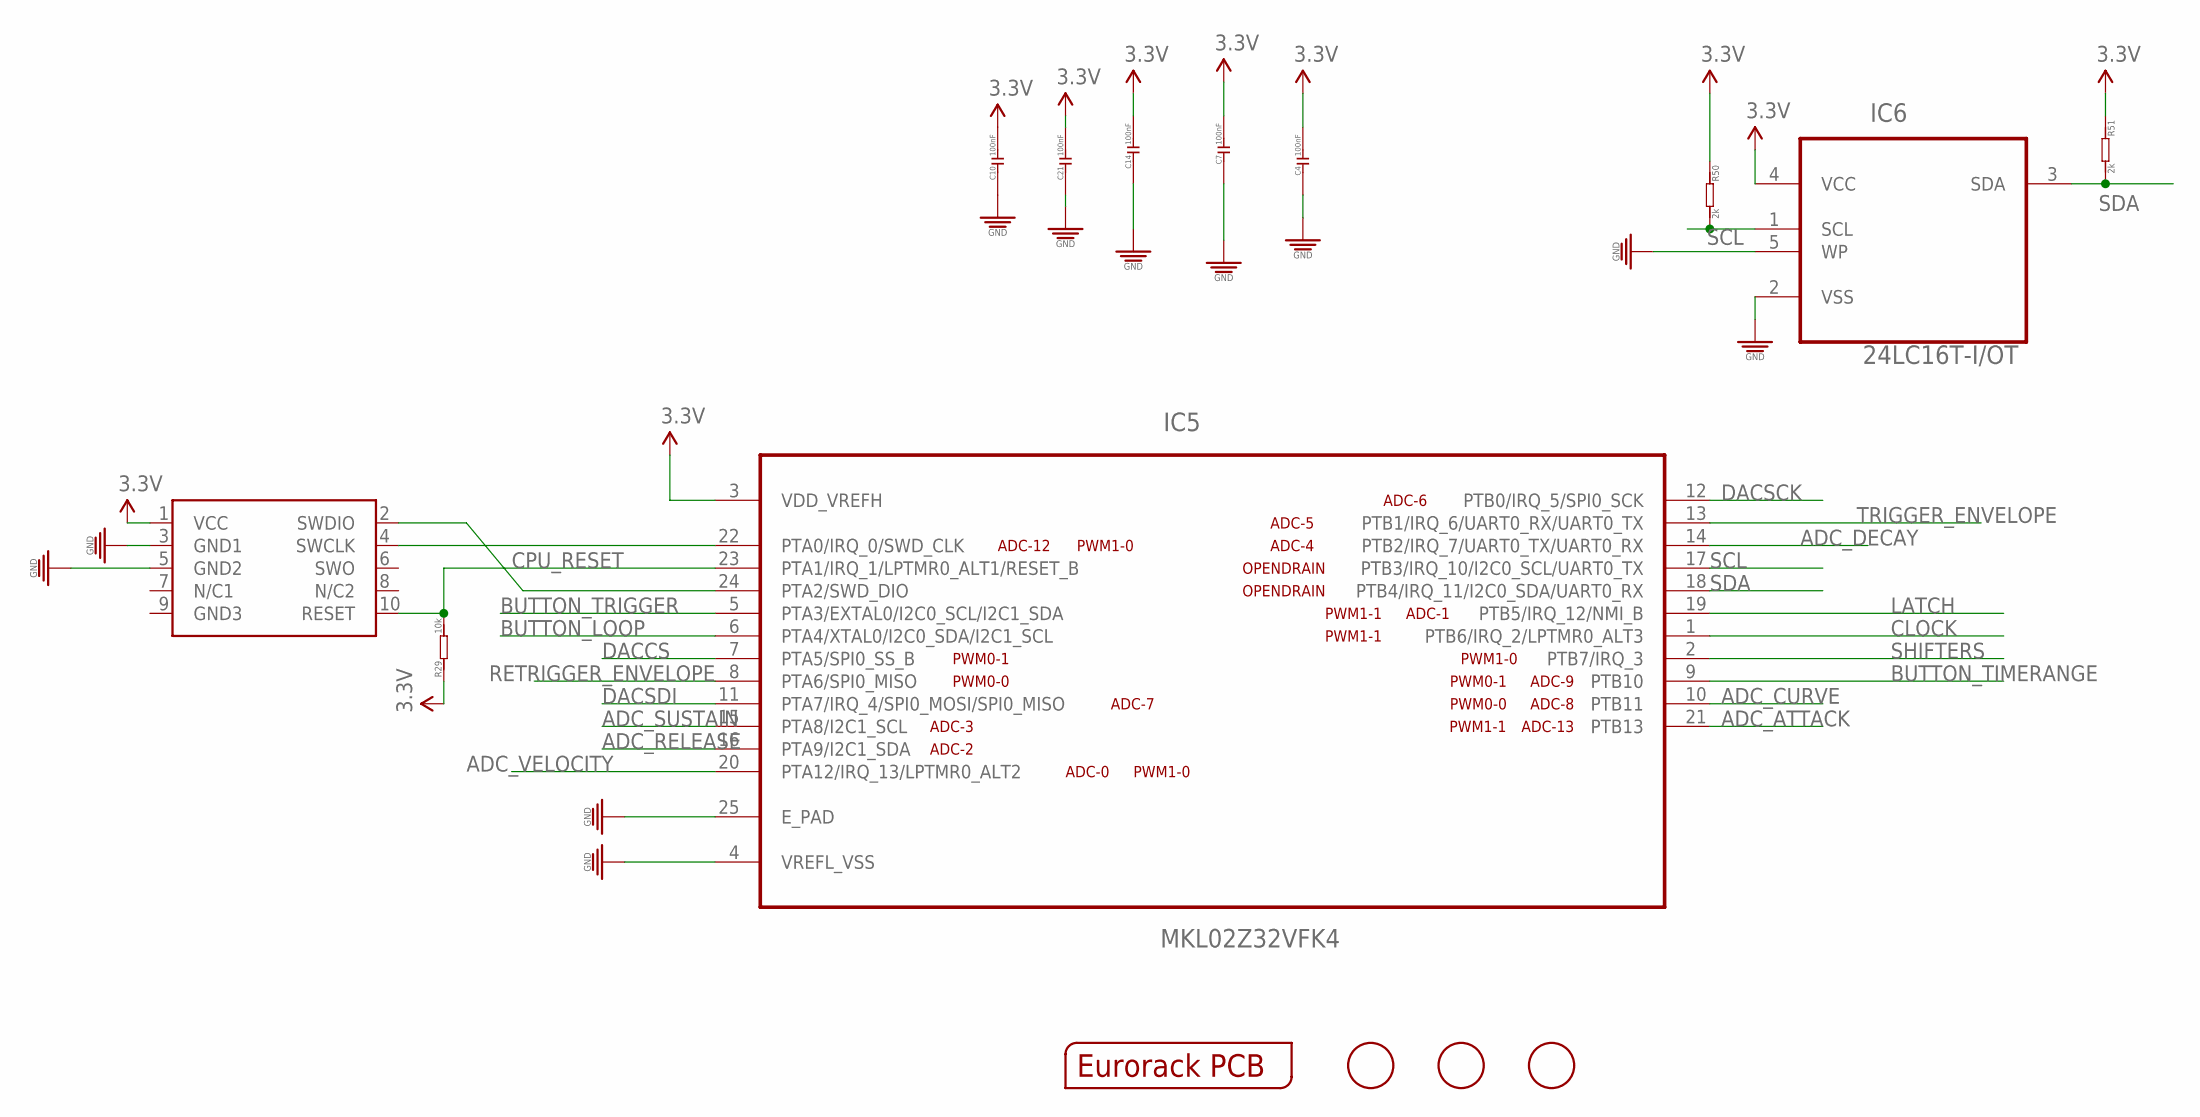
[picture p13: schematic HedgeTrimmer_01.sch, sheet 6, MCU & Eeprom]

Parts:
C4, C7, C10, C14, C21: 100nF; C0603; MPN MC0603F104Z160CT
FID1, FID2, FID3: FIDUCIAL; FIDUCIAL_1MM
IC5: MKL02Z32VFK4; QFN50P400X400X100-25N
IC6: 24LC16T-I/OT; SOT95P290X145-5N; MPN 24LC16T-I/OT
OUTLINE: EURORACK_PCB12HP; EURORACK12HPPCB
R29: 10k; R0603
R50, R51: 2k; R0603
SWD1: CORTEX_SWD; M50-3600542

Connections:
3.3V: C4.2, C7.2, C10.2, C14.2, C21.2, IC5.3 (VDD_VREFH), IC6.4 (VCC), R29.1, R50.1, R51.1, SWD1.1 (VCC); also elsewhere on the board
ADC_ATTACK: IC5.21 (PTB13); also elsewhere on the board
ADC_CURVE: IC5.10 (PTB11); also elsewhere on the board
ADC_DECAY: IC5.14 (PTB2/IRQ_7/UART0_TX/UART0_RX); also elsewhere on the board
ADC_RELEASE: IC5.16 (PTA9/I2C1_SDA); also elsewhere on the board
ADC_SUSTAIN: IC5.15 (PTA8/I2C1_SCL); also elsewhere on the board
ADC_VELOCITY: IC5.20 (PTA12/IRQ_13/LPTMR0_ALT2); also elsewhere on the board
BUTTON_LOOP: IC5.6 (PTA4/XTAL0/I2C0_SDA/I2C1_SCL); also elsewhere on the board
BUTTON_TIMERANGE: IC5.9 (PTB10); also elsewhere on the board
BUTTON_TRIGGER: IC5.5 (PTA3/EXTAL0/I2C0_SCL/I2C1_SDA); also elsewhere on the board
CLOCK: IC5.1 (PTB6/IRQ_2/LPTMR0_ALT3); also elsewhere on the board
CPU_RESET: IC5.23 (PTA1/IRQ_1/LPTMR0_ALT1/RESET_B), R29.2, SWD1.10 (RESET)
DACCS: IC5.7 (PTA5/SPI0_SS_B); also elsewhere on the board
DACSCK: IC5.12 (PTB0/IRQ_5/SPI0_SCK); also elsewhere on the board
DACSDI: IC5.11 (PTA7/IRQ_4/SPI0_MOSI/SPI0_MISO); also elsewhere on the board
GND: C4.1, C7.1, C10.1, C14.1, C21.1, IC5.4 (VREFL_VSS), IC5.25 (E_PAD), IC6.2 (VSS), IC6.5 (WP), SWD1.3 (GND1), SWD1.5 (GND2); also elsewhere on the board
LATCH: IC5.19 (PTB5/IRQ_12/NMI_B); also elsewhere on the board
RETRIGGER_ENVELOPE: IC5.8 (PTA6/SPI0_MISO); also elsewhere on the board
SCL: IC5.17 (PTB3/IRQ_10/I2C0_SCL/UART0_TX), IC6.1 (SCL), R50.2
SDA: IC5.18 (PTB4/IRQ_11/I2C0_SDA/UART0_RX), IC6.3 (SDA), R51.2
SHIFTERS: IC5.2 (PTB7/IRQ_3); also elsewhere on the board
SWD_CLK: IC5.22 (PTA0/IRQ_0/SWD_CLK), SWD1.4 (SWCLK)
SWD_DIO: IC5.24 (PTA2/SWD_DIO), SWD1.2 (SWDIO)
TRIGGER_ENVELOPE: IC5.13 (PTB1/IRQ_6/UART0_RX/UART0_TX); also elsewhere on the board

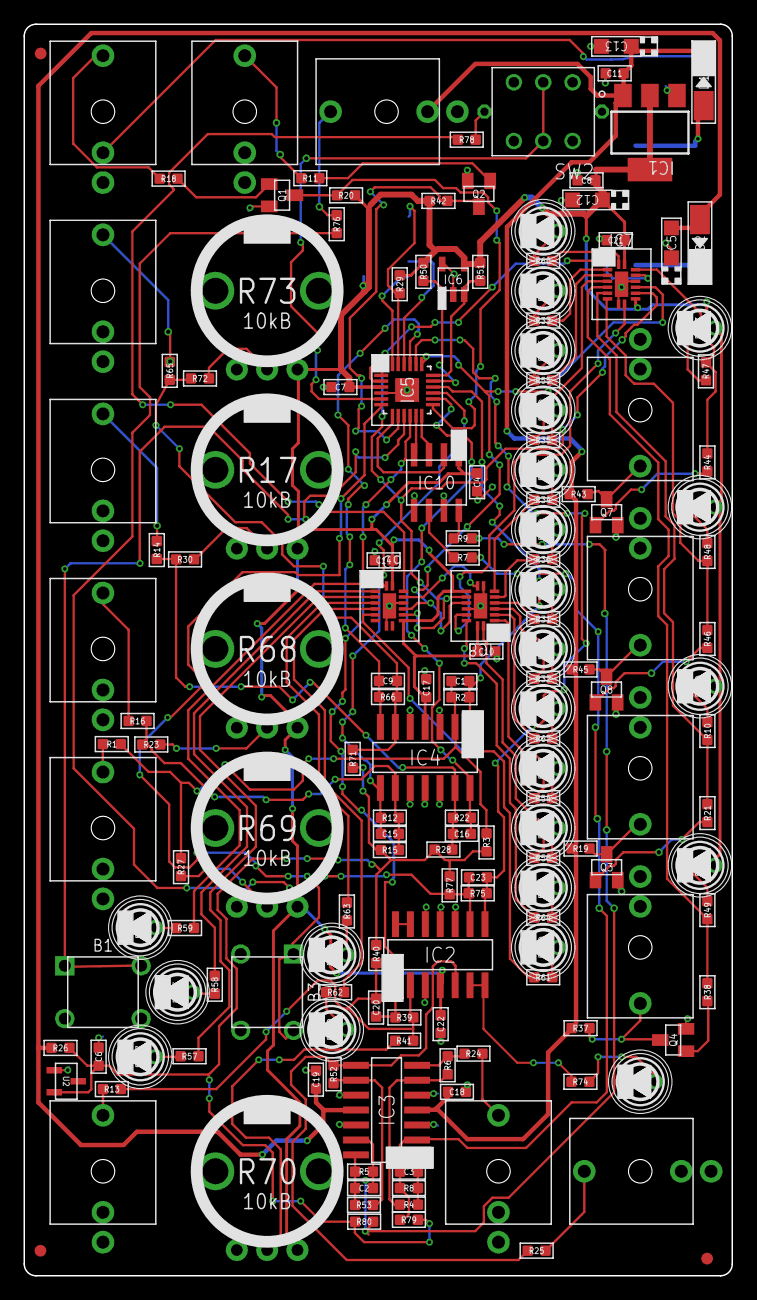
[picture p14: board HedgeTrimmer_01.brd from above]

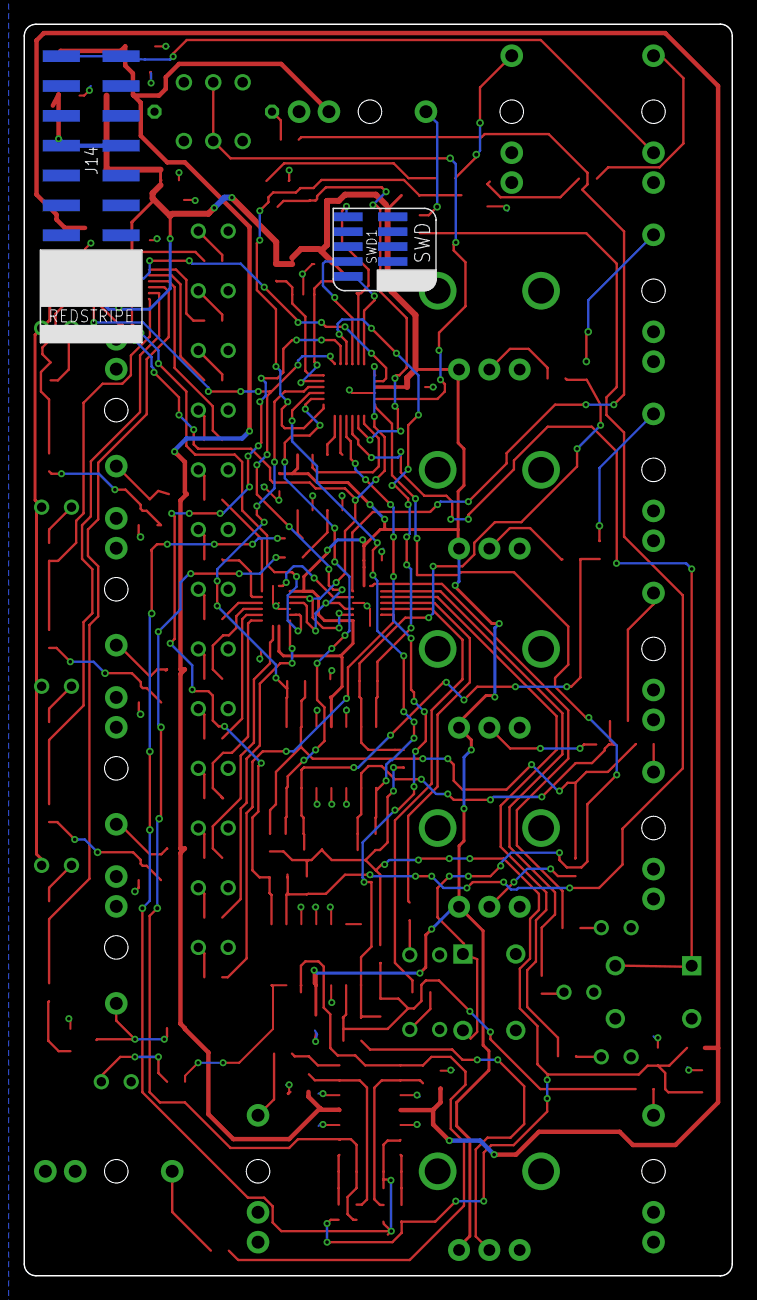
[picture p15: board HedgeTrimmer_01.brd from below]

Board: 2 copper layers, 60.2 x 106.5 mm, 168 parts (2 on the bottom side), 122 nets.

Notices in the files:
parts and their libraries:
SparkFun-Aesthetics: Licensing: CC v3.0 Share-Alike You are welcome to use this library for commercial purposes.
